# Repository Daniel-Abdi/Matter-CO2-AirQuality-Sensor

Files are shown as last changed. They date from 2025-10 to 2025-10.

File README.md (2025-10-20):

## Author: Daniel Abdi

# Introduction

This repo contains code and design files for building your own Matter-based CO2 air quality monitor. The design is based on an ESP32-C6 and SCD40 CO2 sensor, though you can probably replace the SCD40 with any of its cousins in the SCD4x family. It's capable of measuring CO2 in PPM, relative humidity, and the current temperature. Though I only make use of the CO2 measurement in this code. Modifications to add in that functionality are left as an excercise for the reader 😁.  Please note that I'm using ESP-IDF v5.4 and esp-matter at release/v1.4 when compiling. Also note that my code is frankly quite messy and it's doubtful that it adheres to best practices for setting these attributes. Might be worth it to fix later, but this whole project has been more for a fun excercise than anything else. 

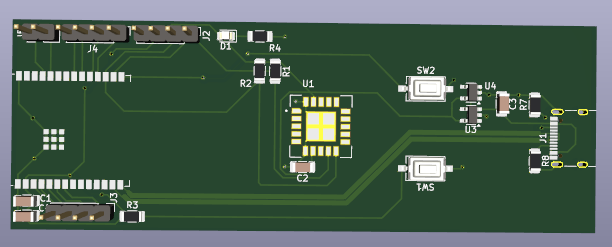
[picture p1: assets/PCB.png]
PCB design, no 3D models for my main components unfortunately


I don't have 3D models of the C6 or the SCD40 so you'll have to use your imagination for those 😆

# How to use it

I make use of a custom board that I designed specifically for this project, so if you'd like to follow my example, you would either have to order a set of boards using the included KiCAD design files, or set up your own example using an ESP32-C6 devkit and a SCD4X breakout board. If you choose to go with your own solution, make sure you change the I2C pins set up within the Sensirion driver folder. I'm going to assume you're somewhat familiar with Matter, esp-matter, ESP-IDF, and KiCAD. Regardless, you should just be able to compile, flash, and pair using a Matter controller you have nearby (I use an Aeotec smart hub).

### Caution with ESP-Matter
 You should also note that depending on which commit of esp-matter you're using, you may run into issues using esp-matter to set the Air Quality value of the Air Quality cluster that is mandatory for the device. Currently, this cluster has a flag of `MANAGED_INTERNALLY`, which means that you need to use the underlying Attribute Accessor Interface (AAI) to set it. That's why those other air-quality-sensor-manager files are included in the repository. Those files are pulled straight from the example in the CHIP repository. If you find that you see an error message where you can't set the value of that attribute using the esp-matter APIs, uncomment the lines in app_main.cpp that represent AAI, and use those functions instead. You can still use esp-matter to set the CO2 concentration. There is also a patch [here](https://github.com/espressif/esp-matter/issues/1548) that you can try and use as well. This should remove that flag and allow you to use esp-matter. You will also need to enable the Air Quality and Carbon Dioxide Concentration clusters in menuconfig for esp-matter. 
 
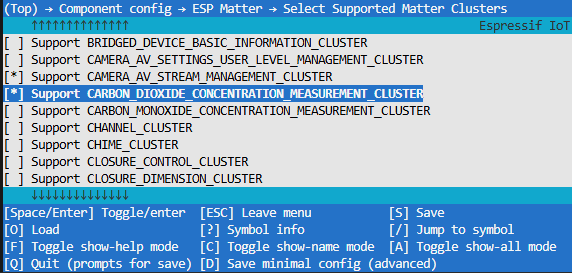
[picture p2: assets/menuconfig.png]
Menuconfig
 

### Pairing
To pair, please use the information at the esp-matter [docs](https://docs.espressif.com/projects/esp-matter/en/latest/esp32/developing.html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). You can use the QR code there to pair to any esp-matter device you create. I've also included the pairing code here for your use.

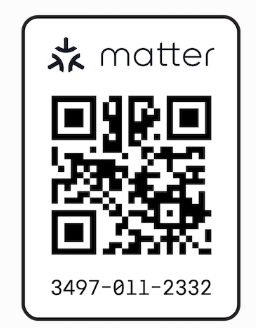
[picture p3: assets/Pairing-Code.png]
Pairing Code


Here's what it'll look like after pairing:

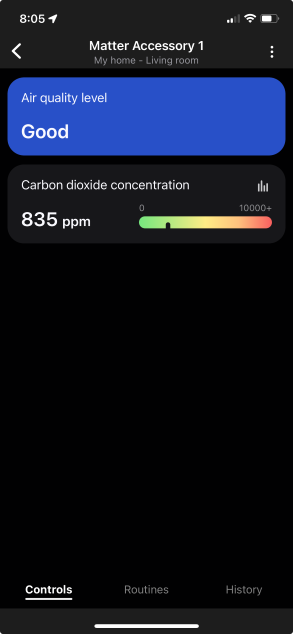
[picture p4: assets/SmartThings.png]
SmartThings


# The Details

The main components of this project are the SCD4X drivers from Sensirion, included in the `/drivers` directory, and `app_main.cpp`, which contains all the code that we really care about. The Sensiron drivers are cloned from  [Here (Github)](https://github.com/Sensirion/embedded-i2c-scd4x/tree/master), with some modifications from my side to work with my custom code (basically adding in the I2C implementation and setting the right pins). I've also included some code from the CHIP repository that represents a way to access attributes using the Attribute Accessor Interface (AAI). Read above on when you might need to use this code, otherwise you can feel free to leave it alone. 

### Clusters
Currently, the device contains 2 clusters of importance to us: The Air Quality cluster, which is mandatory for an Air Quality device, and the CO2 concentration cluster. I've also added the CO2 concentration feature flag, instead of using a level-approach (Like a bad-moderate-good-etc scale) read more in the cluster definitions from the CSA to understand these feature flags and which might work for your use case. Upon commissioning into the Matter fabric, these values are updated every ~5 seconds. SmartThings will be helpful and show you an hourly average of the readings going back 24 hours, so you can see how the CO2 in a space changes over the course of a day or so, even when you aren't looking at the app.

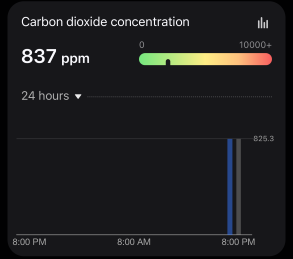
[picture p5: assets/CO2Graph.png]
CO2 Graph


 If you make a change to the features or clusters on the device, make sure to erase-flash, delete from your Matter app, and re-pair, otherwise they may not show up. 

### Using Thread
If you have a Thread border router, you can also enable Thread support and use Matter over Thread with the C6. I haven't done that because I'm not sure if my controller supports Thread and frankly in my use case it doesn't matter as it'd be the only Thread device on the network anyways. 

If you have any questions about my implementation or need help setting up your own, feel free to open an issue and I will try and help.

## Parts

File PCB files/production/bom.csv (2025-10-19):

Designator | Footprint | Quantity | Value | LCSC Part #
C1, C2, C3 | 1206 | 3 | 10uF
C4 | 1206 | 1 | 1uF
D1 | 0805 | 1 | LED
J1 | USB_C_Receptacle_G-Switch_GT-USB-7010ASV | 1 | USB_C_Receptacle_USB2.0_16P
J2, J3, J4 | PinHeader_1x04_P2.54mm_Vertical | 3 | PINHD_1x4_Male
J5 | PinHeader_1x02_P2.54mm_Vertical | 1 | PINHD_1x2_Male
R1, R2, R3 | 1206 | 3 | 10k
R4 | 1206 | 1 | 220
R7, R8 | 1206 | 2 | 5.1k
SW1, SW2 | SW_Tactile_SPST_NO_Straight_CK_PTS636Sx25SMTRLFS | 2 | SW_Push
U1 | XDCR_SCD40-D-R2 | 1 | SCD40-D-R2
U3, U4 | SOT-23-5 | 2 | TLV75533PDBV
U5 | ESP32-C6-WROOM-1 | 1 | ESP32-C6-WROOM-1

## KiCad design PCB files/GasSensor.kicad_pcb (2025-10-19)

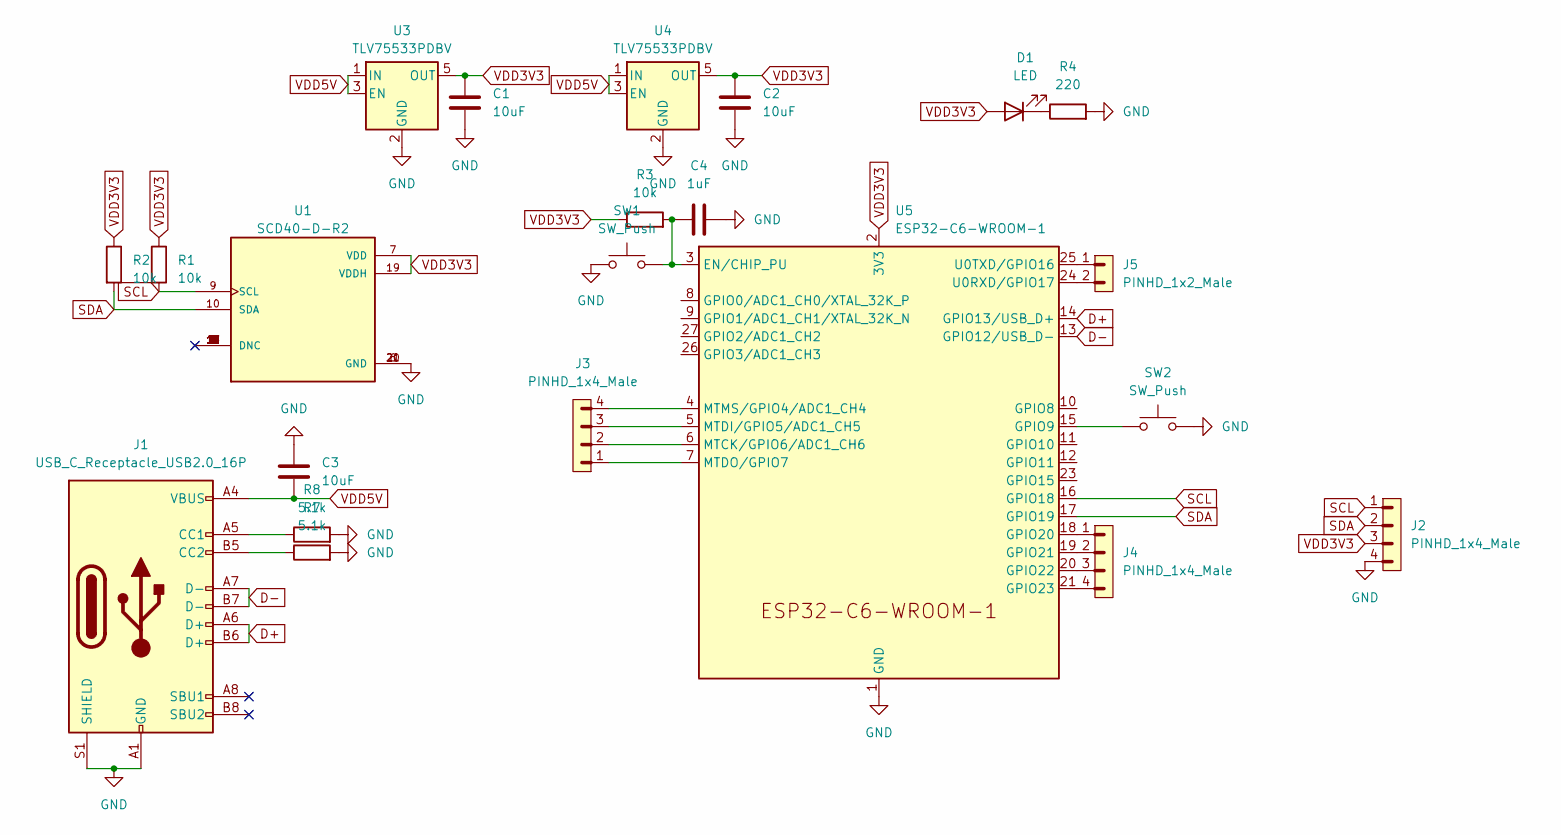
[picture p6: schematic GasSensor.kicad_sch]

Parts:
C1, C2, C3: 10uF; C_1206_3216Metric
C4: 1uF; C_1206_3216Metric
D1: LED; LED_0805_2012Metric
J1: USB_C_Receptacle_USB2.0_16P; USB_C_Receptacle_G-Switch_GT-USB-7010ASV
J2, J3, J4: PINHD_1x4_Male; PinHeader_1x04_P2.54mm_Vertical
J5: PINHD_1x2_Male; PinHeader_1x02_P2.54mm_Vertical
R1, R2, R3: 10k; R_1206_3216Metric
R4: 220; R_1206_3216Metric
R7, R8: 5.1k; R_1206_3216Metric
SW1, SW2: SW_Push; SW_Tactile_SPST_NO_Straight_CK_PTS636Sx25SMTRLFS
U1: SCD40-D-R2; XDCR_SCD40-D-R2; PARTREV 1.2
U3, U4: TLV75533PDBV; SOT-23-5
U5: ESP32-C6-WROOM-1

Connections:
D+: J1.A6 (D+), J1.B6 (D+), U5.14 (GPIO13/USB_D+)
D-: J1.A7 (D-), J1.B7 (D-), U5.13 (GPIO12/USB_D-)
GND: C1.2, C2.2, C3.1, C4.2, J1.A1 (GND), J1.A12 (GND), J1.B1 (GND), J1.B12 (GND), J1.S1 (SHIELD), J2.4, R4.2, R7.2, R8.2, SW1.1, SW2.2, U1.6 (GND), U1.20 (GND), U1.21 (GND), U3.2 (GND), U4.2 (GND), U5.1 (GND), U5.28 (GND), U5.29 (GND)
unnamed: D1.1 (K), R4.1
unnamed: J1.A5 (CC1), R8.1
unnamed: J1.B5 (CC2), R7.1
unnamed: C4.1, R3.2, SW1.2, U5.3 (EN/CHIP_PU)
unnamed: SW2.1, U5.15 (GPIO9)
unnamed: J4.1, U5.18 (GPIO20)
unnamed: J4.2, U5.19 (GPIO21)
unnamed: J4.3, U5.20 (GPIO22)
unnamed: J4.4, U5.21 (GPIO23)
unnamed: J3.2, U5.6 (MTCK/GPIO6/ADC1_CH6)
unnamed: J3.3, U5.5 (MTDI/GPIO5/ADC1_CH5)
unnamed: J3.1, U5.7 (MTDO/GPIO7)
unnamed: J3.4, U5.4 (MTMS/GPIO4/ADC1_CH4)
unnamed: J5.2, U5.24 (U0RXD/GPIO17)
unnamed: J5.1, U5.25 (U0TXD/GPIO16)
SCL: J2.1, R1.2, U1.9 (SCL), U5.16 (GPIO18)
SDA: J2.2, R2.2, U1.10 (SDA), U5.17 (GPIO19)
VDD3V3: C1.1, C2.1, D1.2 (A), J2.3, R1.1, R2.1, R3.1, U1.7 (VDD), U1.19 (VDDH), U3.5 (OUT), U4.5 (OUT), U5.2 (3V3)
VDD5V: C3.2, J1.A4 (VBUS), J1.A9 (VBUS), J1.B4 (VBUS), J1.B9 (VBUS), U3.1 (IN), U3.3 (EN), U4.1 (IN), U4.3 (EN)

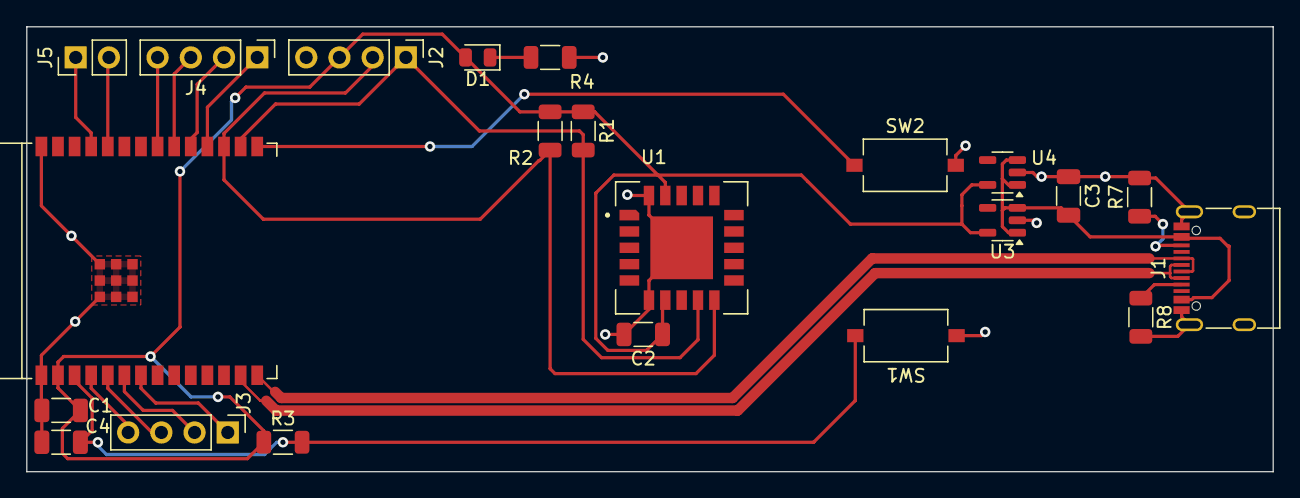
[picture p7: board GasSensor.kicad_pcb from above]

Board: 2 copper layers, 95.3 x 34.0 mm, 22 parts (0 on the bottom side), 22 nets.

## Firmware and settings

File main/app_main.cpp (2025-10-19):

/*
   This example code is in the Public Domain (or CC0 licensed, at your option.)

   Unless required by applicable law or agreed to in writing, this
   software is distributed on an "AS IS" BASIS, WITHOUT WARRANTIES OR
   CONDITIONS OF ANY KIND, either express or implied.
*/

#include <esp_err.h>
#include <esp_log.h>
#include <nvs_flash.h>

#include <esp_matter.h>
#include <esp_matter_console.h>
#include <esp_matter_ota.h>

#include <common_macros.h>
#include <log_heap_numbers.h>

#include <app_priv.h>
#include <app_reset.h>
#if CHIP_DEVICE_CONFIG_ENABLE_THREAD
#include <platform/ESP32/OpenthreadLauncher.h>
#endif


#include <app/server/CommissioningWindowManager.h>
#include <app/server/Server.h>

#ifdef CONFIG_ENABLE_SET_CERT_DECLARATION_API
#include <esp_matter_providers.h>
#include <lib/support/Span.h>
#ifdef CONFIG_SEC_CERT_DAC_PROVIDER
#include <platform/ESP32/ESP32SecureCertDACProvider.h>
#elif defined(CONFIG_FACTORY_PARTITION_DAC_PROVIDER)
#include <platform/ESP32/ESP32FactoryDataProvider.h>
#endif
using namespace chip::DeviceLayer;
#endif
#include <air-quality-sensor-manager.h>

#include "drivers/scd4x_i2c.h"
#include "drivers/sensirion_i2c_hal.h"

static const char *TAG = "app_main";

using namespace esp_matter;
using namespace esp_matter::attribute;
using namespace esp_matter::endpoint;
// using namespace chip::app::Clusters;
using namespace ::chip::app::Clusters;
using namespace ::chip::app::Clusters::AirQuality;

constexpr auto k_timeout_seconds = 300;

#ifdef CONFIG_ENABLE_SET_CERT_DECLARATION_API
extern const uint8_t cd_start[] asm("_binary_certification_declaration_der_start");
extern const uint8_t cd_end[] asm("_binary_certification_declaration_der_end");

const chip::ByteSpan cdSpan(cd_start, static_cast<size_t>(cd_end - cd_start));
#endif // CONFIG_ENABLE_SET_CERT_DECLARATION_API

#if CONFIG_ENABLE_ENCRYPTED_OTA
extern const char decryption_key_start[] asm("_binary_esp_image_encryption_key_pem_start");
extern const char decryption_key_end[] asm("_binary_esp_image_encryption_key_pem_end");

static const char *s_decryption_key = decryption_key_start;
static const uint16_t s_decryption_key_len = decryption_key_end - decryption_key_start;
#endif // CONFIG_ENABLE_ENCRYPTED_OTA

static void app_event_cb(const ChipDeviceEvent *event, intptr_t arg)
{
    switch (event->Type) {
    case chip::DeviceLayer::DeviceEventType::kInterfaceIpAddressChanged:
        ESP_LOGI(TAG, "Interface IP Address changed");
        break;

    case chip::DeviceLayer::DeviceEventType::kCommissioningComplete:
        ESP_LOGI(TAG, "Commissioning complete");
        MEMORY_PROFILER_DUMP_HEAP_STAT("commissioning complete");
        break;

    case chip::DeviceLayer::DeviceEventType::kFailSafeTimerExpired:
        ESP_LOGI(TAG, "Commissioning failed, fail safe timer expired");
        break;

    case chip::DeviceLayer::DeviceEventType::kCommissioningSessionStarted:
        ESP_LOGI(TAG, "Commissioning session started");
        break;

    case chip::DeviceLayer::DeviceEventType::kCommissioningSessionStopped:
        ESP_LOGI(TAG, "Commissioning session stopped");
        break;

    case chip::DeviceLayer::DeviceEventType::kCommissioningWindowOpened:
        ESP_LOGI(TAG, "Commissioning window opened");
        MEMORY_PROFILER_DUMP_HEAP_STAT("commissioning window opened");
        break;

    case chip::DeviceLayer::DeviceEventType::kCommissioningWindowClosed:
        ESP_LOGI(TAG, "Commissioning window closed");
        break;

    case chip::DeviceLayer::DeviceEventType::kFabricRemoved:
        {
            ESP_LOGI(TAG, "Fabric removed successfully");
            if (chip::Server::GetInstance().GetFabricTable().FabricCount() == 0)
            {
                chip::CommissioningWindowManager & commissionMgr = chip::Server::GetInstance().GetCommissioningWindowManager();
                constexpr auto kTimeoutSeconds = chip::System::Clock::Seconds16(k_timeout_seconds);
                if (!commissionMgr.IsCommissioningWindowOpen())
                {
                    /* After removing last fabric, this example does not remove the Wi-Fi credentials
                     * and still has IP connectivity so, only advertising on DNS-SD.
                     */
                    CHIP_ERROR err = commissionMgr.OpenBasicCommissioningWindow(kTimeoutSeconds,
                                                    chip::CommissioningWindowAdvertisement::kDnssdOnly);
                    if (err != CHIP_NO_ERROR)
                    {
                        ESP_LOGE(TAG, "Failed to open commissioning window, err:%" CHIP_ERROR_FORMAT, err.Format());
                    }
                }
            }
        break;
        }

    case chip::DeviceLayer::DeviceEventType::kFabricWillBeRemoved:
        ESP_LOGI(TAG, "Fabric will be removed");
        break;

    case chip::DeviceLayer::DeviceEventType::kFabricUpdated:
        ESP_LOGI(TAG, "Fabric is updated");
        break;

    case chip::DeviceLayer::DeviceEventType::kFabricCommitted:
        ESP_LOGI(TAG, "Fabric is committed");
        break;

    case chip::DeviceLayer::DeviceEventType::kBLEDeinitialized:
        ESP_LOGI(TAG, "BLE deinitialized and memory reclaimed");
        MEMORY_PROFILER_DUMP_HEAP_STAT("BLE deinitialized");
        break;

    default:
        break;
    }
}


uint16_t qual_endpoint;
// This callback is invoked when clients interact with the Identify Cluster.
// In the callback implementation, an endpoint can identify itself. (e.g., by flashing an LED or light).
static esp_err_t app_identification_cb(identification::callback_type_t type, uint16_t endpoint_id, uint8_t effect_id,
                                       uint8_t effect_variant, void *priv_data)
{
    ESP_LOGI(TAG, "Identification callback: type: %u, effect: %u, variant: %u", type, effect_id, effect_variant);
    return ESP_OK;
}

// This callback is called for every attribute update. The callback implementation shall
// handle the desired attributes and return an appropriate error code. If the attribute
// is not of your interest, please do not return an error code and strictly return ESP_OK.
static esp_err_t app_attribute_update_cb(attribute::callback_type_t type, uint16_t endpoint_id, uint32_t cluster_id,
                                         uint32_t attribute_id, esp_matter_attr_val_t *val, void *priv_data)
{
    esp_err_t err = ESP_OK;

    if (type == PRE_UPDATE) {
        /* Driver update */
        // app_driver_handle_t driver_handle = (app_driver_handle_t)priv_data;
        // err = app_driver_attribute_update(driver_handle, endpoint_id, cluster_id, attribute_id, val);
    }

    return err;
}

static void sensor_update_task(void *pvParameters)
{
    uint16_t endpoint_id = qual_endpoint;
    
    ESP_LOGI(TAG, "Waiting for Matter stack to initialize...");
    vTaskDelay(5000 / portTICK_PERIOD_MS);
    
    while (true) {

        
        // Update CO2 concentration
        
        chip::DeviceLayer::PlatformMgr().LockChipStack();


        uint16_t co2_measurement; 
        int32_t temp_measurement;
        int32_t humidity_measurement;
        scd4x_read_measurement(&co2_measurement, &temp_measurement, &humidity_measurement); 
        uint16_t co2_value = co2_measurement;
        ESP_LOGI(TAG, "MEASUREMENTS: %d, %lu, %lu", co2_measurement, temp_measurement, humidity_measurement);

        //UNCOMMENT THESE IF USING AAI
        // AirQualitySensorManager * mInstance = AirQualitySensorManager::GetInstance();
        // mInstance->OnAirQualityChangeHandler(AirQualityEnum::kGood);
        ESP_LOGI(TAG, "CO2: %d", co2_value);

        // mInstance->OnCarbonDioxideMeasurementChangeHandler(co2_value);
        
        //Note that from what I remember, the feature flags for air quality aren't really set by us. Maybe handled by esp-matter, idk, but 
        //The only flags that exist are all optional and are for supporting fair, moderate, very poor, and extremely poor air quality. 
        //value 1 is good, value 2 is fair, 3 is moderate, 4 is poor. Value 0 is unknown.

        int8_t air_quality_value_int = 0;
        //this is a quick and dirty way of setting this. Consider making it less terrible later. Also, these categories are completely arbitrary.
        if(co2_value <= 1000)
        {
            air_quality_value_int = 1;
        }
        else if(co2_value <= 2500)
        {
            air_quality_value_int = 2;
        }
        else if(co2_value <= 5000)
        {
            air_quality_value_int = 3;
        }
        else
        {
            air_quality_value_int = 4;
        }
        esp_matter_attr_val_t air_qual_val = esp_matter_enum8(air_quality_value_int);

        esp_matter::attribute::update(endpoint_id, AirQuality::Id, AirQuality::Attributes::AirQuality::Id, &air_qual_val);

        esp_matter_attr_val_t co2_val = esp_matter_nullable_float(co2_measurement);
        esp_matter::attribute::update(endpoint_id, 
                                     CarbonDioxideConcentrationMeasurement::Id,
                                     CarbonDioxideConcentrationMeasurement::Attributes::MeasuredValue::Id,
                                     &co2_val);
        chip::DeviceLayer::PlatformMgr().UnlockChipStack();

        vTaskDelay(5000 / portTICK_PERIOD_MS);
    }
}

extern "C" void app_main()
{
    esp_err_t err = ESP_OK;

    /* Initialize the ESP NVS layer */
    nvs_flash_init();

    MEMORY_PROFILER_DUMP_HEAP_STAT("Bootup");

    /* Initialize driver */
    sensirion_i2c_hal_init();
    scd4x_init(0x62);

    /* Create a Matter node and add the mandatory Root Node device type on endpoint 0 */
    node::config_t node_config;

    // node handle can be used to add/modify other endpoints.
    node_t *node = node::create(&node_config, app_attribute_update_cb, app_identification_cb);
    ABORT_APP_ON_FAILURE(node != nullptr, ESP_LOGE(TAG, "Failed to create Matter node"));

    MEMORY_PROFILER_DUMP_HEAP_STAT("node created");

    air_quality_sensor::config_t air_quality_sensor_config;

    endpoint_t *air_qual_ep = air_quality_sensor::create(node, &air_quality_sensor_config, ENDPOINT_FLAG_NONE, NULL);
    //note that the air quality cluster is automagically created by the air quality endpoint? This part isn't 100% clear to me, and it seems like it's changing on
    //the esp-matter side too. Remember to keep watch on this. 

    //cluster_t *aq_cluster_def = esp_matter::cluster::air_quality::create(air_qual_ep, &air_quality_sensor_config.air_quality, CLUSTER_FLAG_SERVER);

    esp_matter::cluster::concentration_measurement::config_t co2_config;

    // Set measurement medium to Air (typically 0x00)
    co2_config.measurement_medium = 0x00; // Air

    // Configure the mandatory numeric measurement feature for CO2
    co2_config.features.numeric_measurement.min_measured_value = 0.0f;
    co2_config.features.numeric_measurement.max_measured_value = 10000.0f; // Typical CO2 sensors go up to 5000 ppm
    co2_config.features.numeric_measurement.measured_value = 400.0f; // Initialize to typical ambient CO2
    co2_config.features.numeric_measurement.measurement_unit = 0; // Parts per million

    // Set feature flags for numeric measurement
    co2_config.feature_flags = 1;

    // Delegate can be set later if needed
    co2_config.delegate = nullptr;

    // Create the cluster instance
    cluster_t *cluster = esp_matter::cluster::carbon_dioxide_concentration_measurement::create(air_qual_ep, &co2_config, CLUSTER_FLAG_SERVER);

    qual_endpoint = endpoint::get_id(air_qual_ep);

    ABORT_APP_ON_FAILURE(air_qual_ep != nullptr, ESP_LOGE(TAG, "Failed to create air quality sensor endpoint"));
    
    //UNCOMMENT THIS IF USING AAI.
    // AirQualitySensorManager::InitInstance(qual_endpoint);

    //init scd40 here

    sensirion_i2c_hal_init();
    vTaskDelay(100 / portTICK_PERIOD_MS);
    scd4x_start_periodic_measurement();


#if CHIP_DEVICE_CONFIG_ENABLE_THREAD && CHIP_DEVICE_CONFIG_ENABLE_WIFI_STATION
    // Enable secondary network interface
    secondary_network_interface::config_t secondary_network_interface_config;
    endpoint = endpoint::secondary_network_interface::create(node, &secondary_network_interface_config, ENDPOINT_FLAG_NONE, nullptr);
    ABORT_APP_ON_FAILURE(endpoint != nullptr, ESP_LOGE(TAG, "Failed to create secondary network interface endpoint"));
#endif


#if CHIP_DEVICE_CONFIG_ENABLE_THREAD
    /* Set OpenThread platform config */
    esp_openthread_platform_config_t config = {
        .radio_config = ESP_OPENTHREAD_DEFAULT_RADIO_CONFIG(),
        .host_config = ESP_OPENTHREAD_DEFAULT_HOST_CONFIG(),
        .port_config = ESP_OPENTHREAD_DEFAULT_PORT_CONFIG(),
    };
    set_openthread_platform_config(&config);
#endif

#ifdef CONFIG_ENABLE_SET_CERT_DECLARATION_API
    auto * dac_provider = get_dac_provider();
#ifdef CONFIG_SEC_CERT_DAC_PROVIDER
    static_cast<ESP32SecureCertDACProvider *>(dac_provider)->SetCertificationDeclaration(cdSpan);
#elif defined(CONFIG_FACTORY_PARTITION_DAC_PROVIDER)
    static_cast<ESP32FactoryDataProvider *>(dac_provider)->SetCertificationDeclaration(cdSpan);
#endif
#endif // CONFIG_ENABLE_SET_CERT_DECLARATION_API

    /* Matter start */
    err = esp_matter::start(app_event_cb);
    ABORT_APP_ON_FAILURE(err == ESP_OK, ESP_LOGE(TAG, "Failed to start Matter, err:%d", err));

    MEMORY_PROFILER_DUMP_HEAP_STAT("matter started");

    /* Starting driver with default values */

#if CONFIG_ENABLE_ENCRYPTED_OTA
    err = esp_matter_ota_requestor_encrypted_init(s_decryption_key, s_decryption_key_len);
    ABORT_APP_ON_FAILURE(err == ESP_OK, ESP_LOGE(TAG, "Failed to initialized the encrypted OTA, err: %d", err));
#endif // CONFIG_ENABLE_ENCRYPTED_OTA

#if CONFIG_ENABLE_CHIP_SHELL
    esp_matter::console::diagnostics_register_commands();
    esp_matter::console::wifi_register_commands();
    esp_matter::console::factoryreset_register_commands();
    esp_matter::console::attribute_register_commands();
#if CONFIG_OPENTHREAD_CLI
    esp_matter::console::otcli_register_commands();
#endif
    esp_matter::console::init();
#endif
    xTaskCreate(sensor_update_task, "sensor_update", 4096, NULL, 5, NULL);

    while (true) {
        MEMORY_PROFILER_DUMP_HEAP_STAT("Idle");
        vTaskDelay(10000 / portTICK_PERIOD_MS);
    }
}

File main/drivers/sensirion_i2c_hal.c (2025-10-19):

/*
 * Copyright (c) 2018, Sensirion AG
 * All rights reserved.
 *
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
 * * Neither the name of Sensirion AG nor the names of its
 *   contributors may be used to endorse or promote products derived from
 *   this software without specific prior written permission.
 *
 * THIS SOFTWARE IS PROVIDED BY THE COPYRIGHT HOLDERS AND CONTRIBUTORS "AS IS"
 * AND ANY EXPRESS OR IMPLIED WARRANTIES, INCLUDING, BUT NOT LIMITED TO, THE
 * IMPLIED WARRANTIES OF MERCHANTABILITY AND FITNESS FOR A PARTICULAR PURPOSE
 * ARE DISCLAIMED. IN NO EVENT SHALL THE COPYRIGHT HOLDER OR CONTRIBUTORS BE
 * LIABLE FOR ANY DIRECT, INDIRECT, INCIDENTAL, SPECIAL, EXEMPLARY, OR
 * CONSEQUENTIAL DAMAGES (INCLUDING, BUT NOT LIMITED TO, PROCUREMENT OF
 * SUBSTITUTE GOODS OR SERVICES; LOSS OF USE, DATA, OR PROFITS; OR BUSINESS
 * INTERRUPTION) HOWEVER CAUSED AND ON ANY THEORY OF LIABILITY, WHETHER IN
 * CONTRACT, STRICT LIABILITY, OR TORT (INCLUDING NEGLIGENCE OR OTHERWISE)
 * ARISING IN ANY WAY OUT OF THE USE OF THIS SOFTWARE, EVEN IF ADVISED OF THE
 * POSSIBILITY OF SUCH DAMAGE.
 */

#include "sensirion_i2c_hal.h"
#include "sensirion_common.h"
#include "sensirion_config.h"

#include "driver/i2c_master.h"
#include "esp_log.h"
#include "freertos/FreeRTOS.h"
#include "freertos/task.h"

static const char* TAG = "sensirion_i2c_hal";

// Configure these according to your hardware setup
#define I2C_MASTER_SCL_IO           18      // GPIO number for I2C SCL
#define I2C_MASTER_SDA_IO           19      // GPIO number for I2C SDA
#define I2C_MASTER_FREQ_HZ          100000 // I2C master clock frequency
#define I2C_MASTER_TIMEOUT_MS       1000

static i2c_master_bus_handle_t i2c_bus_handle = NULL;

/**
 * Select the current i2c bus by index.
 * All following i2c operations will be directed at that bus.
 *
 * THE IMPLEMENTATION IS OPTIONAL ON SINGLE-BUS SETUPS (all sensors on the same
 * bus)
 *
 * @param bus_idx   Bus index to select
 * @returns         0 on success, an error code otherwise
 */
int16_t sensirion_i2c_hal_select_bus(uint8_t bus_idx) {
    // Optional - leave empty for single-bus setup
    return NOT_IMPLEMENTED_ERROR;
}

/**
 * Initialize all hard- and software components that are needed for the I2C
 * communication.
 */
void sensirion_i2c_hal_init(void) {
    if (i2c_bus_handle != NULL) {
        ESP_LOGW(TAG, "I2C already initialized");
        return;
    }

    i2c_master_bus_config_t i2c_bus_config = {
        .clk_source = I2C_CLK_SRC_DEFAULT,
        .i2c_port = I2C_NUM_0,
        .scl_io_num = I2C_MASTER_SCL_IO,
        .sda_io_num = I2C_MASTER_SDA_IO,
        .glitch_ignore_cnt = 7,
        .flags.enable_internal_pullup = true,
    };

    esp_err_t err = i2c_new_master_bus(&i2c_bus_config, &i2c_bus_handle);
    if (err != ESP_OK) {
        ESP_LOGE(TAG, "Failed to initialize I2C master bus: %s", esp_err_to_name(err));
        i2c_bus_handle = NULL;
    } else {
        ESP_LOGI(TAG, "I2C master bus initialized successfully");
    }
}

/**
 * Release all resources initialized by sensirion_i2c_hal_init().
 */
void sensirion_i2c_hal_free(void) {
    if (i2c_bus_handle != NULL) {
        i2c_del_master_bus(i2c_bus_handle);
        i2c_bus_handle = NULL;
        ESP_LOGI(TAG, "I2C master bus deleted");
    }
}

/**
 * Execute one read transaction on the I2C bus, reading a given number of bytes.
 * If the device does not acknowledge the read command, an error shall be
 * returned.
 *
 * @param address 7-bit I2C address to read from
 * @param data    pointer to the buffer where the data is to be stored
 * @param count   number of bytes to read from I2C and store in the buffer
 * @returns 0 on success, error code otherwise
 */
int8_t sensirion_i2c_hal_read(uint8_t address, uint8_t* data, uint8_t count) {
    if (i2c_bus_handle == NULL) {
        ESP_LOGE(TAG, "I2C not initialized");
        return -1;
    }

    // Add device to bus (temporary device handle)
    i2c_device_config_t dev_cfg = {
        .dev_addr_length = I2C_ADDR_BIT_LEN_7,
        .device_address = address,
        .scl_speed_hz = I2C_MASTER_FREQ_HZ,
    };

    i2c_master_dev_handle_t dev_handle;
    esp_err_t err = i2c_master_bus_add_device(i2c_bus_handle, &dev_cfg, &dev_handle);
    if (err != ESP_OK) {
        ESP_LOGE(TAG, "Failed to add device: %s", esp_err_to_name(err));
        return -1;
    }

    // Perform read transaction
    err = i2c_master_receive(dev_handle, data, count, I2C_MASTER_TIMEOUT_MS);
    
    // Remove device from bus
    i2c_master_bus_rm_device(dev_handle);

    if (err != ESP_OK) {
        ESP_LOGE(TAG, "I2C read failed: %s", esp_err_to_name(err));
        return -1;
    }

    return 0;
}

/**
 * Execute one write transaction on the I2C bus, sending a given number of
 * bytes. The bytes in the supplied buffer must be sent to the given address. If
 * the slave device does not acknowledge any of the bytes, an error shall be
 * returned.
 *
 * @param address 7-bit I2C address to write to
 * @param data    pointer to the buffer containing the data to write
 * @param count   number of bytes to read from the buffer and send over I2C
 * @returns 0 on success, error code otherwise
 */
int8_t sensirion_i2c_hal_write(uint8_t address, const uint8_t* data,
                               uint8_t count) {
    if (i2c_bus_handle == NULL) {
        ESP_LOGE(TAG, "I2C not initialized");
        return -1;
    }

    // Add device to bus (temporary device handle)
    i2c_device_config_t dev_cfg = {
        .dev_addr_length = I2C_ADDR_BIT_LEN_7,
        .device_address = address,
        .scl_speed_hz = I2C_MASTER_FREQ_HZ,
    };

    i2c_master_dev_handle_t dev_handle;
    esp_err_t err = i2c_master_bus_add_device(i2c_bus_handle, &dev_cfg, &dev_handle);
    if (err != ESP_OK) {
        ESP_LOGE(TAG, "Failed to add device: %s", esp_err_to_name(err));
        return -1;
    }

    // Perform write transaction
    err = i2c_master_transmit(dev_handle, data, count, I2C_MASTER_TIMEOUT_MS);
    
    // Remove device from bus
    i2c_master_bus_rm_device(dev_handle);

    if (err != ESP_OK) {
        ESP_LOGE(TAG, "I2C write failed: %s", esp_err_to_name(err));
        return -1;
    }

    return 0;
}

/**
 * Sleep for a given number of microseconds. The function should delay the
 * execution for at least the given time, but may also sleep longer.
 *
 * Despite the unit, a <10 millisecond precision is sufficient.
 *
 * @param useconds the sleep time in microseconds
 */
void sensirion_i2c_hal_sleep_usec(uint32_t useconds) {
    // Convert microseconds to ticks (minimum 1 tick)
    uint32_t ticks = useconds / (1000 * portTICK_PERIOD_MS);
    if (ticks == 0) {
        ticks = 1;
    }
    vTaskDelay(ticks);
}
